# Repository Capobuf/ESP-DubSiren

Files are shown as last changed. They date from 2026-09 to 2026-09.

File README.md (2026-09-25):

# ESP32-S3 Dub Siren

Dub siren controllata da una GUI Windows. Il DSP gira interamente sull'ESP32-S3
e il PCM mono già elaborato può essere inviato al PC, a un DAC PCM5102A via
I2S, oppure a entrambe le destinazioni senza resampling.

Il motore V2 usa oscillatori pulse PolyBLEP, shaping RC mode-specifico,
saturazione asimmetrica e un LFO CLASSIC a carica/scarica esponenziale. Il
comando di debug `SET VOICING LEGACY|V2` permette il confronto a parità di
controlli; V2 è il default.

## Requisiti Windows

- ESP32-S3 DevKitC-1 collegata con un cavo USB dati
- modulo DAC PCM5102A per l'uscita audio GPIO
- VS Code con estensione PlatformIO IDE, oppure PlatformIO Core 6.x
- Python 3.11 o successivo (verificato con Python 3.13.14)
- uscita audio Windows

La configurazione usa il profilo PlatformIO base `esp32-s3-devkitc-1`, Hardware
CDC e USB Serial/JTAG. Non abilita PSRAM né imposta modalità flash specifiche.

## Preparazione

Aprire un prompt nella cartella `pc` ed eseguire una volta:

```bat
setup.bat
```

Lo script crea `.venv`, aggiorna pip e installa `pyserial` e `sounddevice`.

## Build e upload firmware

Da un terminale nella cartella `firmware`:

```powershell
python -m platformio run
python -m platformio run --target upload --upload-port COM6
```

Sostituire `COM6` con la porta effettiva. Usare la connessione USB nativa che
Windows identifica come Espressif USB Serial/JTAG (`VID 303A`, `PID 1001`), non
una porta Bluetooth. Al primo upload può essere necessario entrare nel
bootloader: tenere premuto **BOOT**, premere e rilasciare **RESET/EN**, quindi
rilasciare **BOOT**. Dopo l'upload, se resta nel bootloader, premere una volta
solo **RESET/EN**.

In VS Code sono equivalenti i comandi **PlatformIO: Build** e
**PlatformIO: Upload**.

## Collegamento PCM5102A

Il DAC usa I2S Philips standard a 48 kHz, stereo 16 bit. Il firmware duplica
ogni campione mono sui canali sinistro e destro; il PCM5102A ricava internamente
il clock necessario e non richiede MCLK dall'ESP32.

```text
ESP32 GPIO16 -> PCM5102A BCK
ESP32 GPIO17 -> PCM5102A LCK
ESP32 GPIO18 -> PCM5102A DIN
PCM5102A SCL/SCK -> GND
PCM5102A FMT -> GND
```

## Avvio

Dalla cartella `pc`:

```bat
run.bat
```

La GUI si apre anche senza ESP collegata. Poi:

1. premere **Refresh** e scegliere la COM Espressif;
2. scegliere **PC**, **PCM5102A** o **Both** nel selettore Output;
3. premere **Connect** e attendere `Connected · firmware 0.4.0`;
4. premere **Start Audio**;
5. usare **TRIGGER** oppure attivare **HOLD**.

**Stop Audio** arresta il flusso; **Disconnect** chiude ordinatamente audio,
thread e seriale. Per un controllo automatico dell'hardware collegato:

```powershell
.venv\Scripts\python.exe smoke_test.py COM6
```

Dettagli: [architettura](docs/architecture.md), [protocollo](docs/protocol.md) e
[controlli](docs/controls.md).

Per creare dieci brevi WAV di confronto direttamente dal PCM firmware (con la
scheda collegata), eseguire dalla cartella `pc`:

```powershell
.venv\Scripts\python.exe performance_capture.py COM6
```

Lo script stampa la directory temporanea che contiene i WAV. Usare
`--output-dir <percorso>` per scegliere una destinazione persistente. Il profilo
CLASSIC offre preset di progetto, non una riproduzione misurata di altri modelli.

## Test

```powershell
pc\.venv\Scripts\python.exe -m unittest discover -s pc -p "test_*.py"
pc\.venv\Scripts\python.exe tests\native\run.py
pc\.venv\Scripts\python.exe -m platformio run -d firmware
```

Il test nativo usa Zig C++ (`pip install ziglang`) oppure il compilatore indicato
da `CXX`; esegue parser e DSP senza scheda. Con hardware collegato, leggere
`renderUs`, `maxRenderUs`, `cycleUs` e `maxCycleUs` da STATUS durante gli scenari
di sweep e verificare che restino sotto 10.000 µs per blocco.

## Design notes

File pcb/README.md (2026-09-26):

# ESP-DubSiren PCB V0

Questa revisione e una piattaforma di verifica meccanica ed elettrica, non un progetto autorizzato alla fabbricazione. Serve a verificare nel materiale reale l'ingombro nel box Hammond 29830PSLA, l'ergonomia dei controlli, le forature, lo stack verticale e i due moduli montati sul retro.

## Stato della revisione

- PCB: 98.00 x 72.00 mm, angoli R6.00 mm, 2 layer, FR4 1.6 mm, rame standard.
- Origine PCB: angolo superiore sinistro dell'Edge.Cuts; X verso destra, Y verso il basso.
- Regole V0: clearance 0.20 mm, pista minima 0.20 mm, via 0.60/0.30 mm, foro-foro 0.25 mm.
- Controlli sul lato frontale; ESP32-S3 DevKitC-1 e breakout PCM5102A sul lato posteriore.
- I2S e alimentazioni sono instradati; GND e su entrambi i piani. I dieci segnali di controllo restano intenzionalmente non assegnati a GPIO.
- Il progetto e valido come V0 di verifica, ma **non deve essere mandato in produzione prima delle misure elencate sotto**.

## Box e derivazione delle dimensioni PCB

Box di riferimento: Hammond / Eddystone 29830PSLA.

Dal drawing ufficiale:

- esterno: 120.80 x 95.50 x 33.80 mm;
- vano interno del corpo: 104.71 x 79.41 mm;
- zona interna del lid: 102.83 x 77.13 mm;
- profondita interna nominale del corpo: circa 29.70-30.00 mm;
- spessore coperchio: 2.10 mm;
- interassi dei quattro bossoli: 110.75 x 85.75 mm.

La PCB 98 x 72 mm lascia rispetto alla zona interna del lid 4.83 mm totali in X e 5.13 mm totali in Y, cioe circa 2.42 e 2.57 mm per lato se centrata. Rispetto al vano del corpo lascia circa 3.36 mm per lato in X e 3.71 mm per lato in Y. Gli angoli R6 evitano i bossoli; il margine geometrico minimo tra arco PCB e bossolo nominale e circa 6.3 mm.

`MECH1`, centrato in (49, 36), e un riferimento board-only: su `Dwgs.User` contiene perimetro esterno, vano interno, zona interna del lid e quattro bossoli. Il modello STEP Hammond ufficiale e associato allo stesso riferimento, ruotato per allineare il piano del box alla PCB. Lo STEP rappresenta il box chiuso e quindi oscura la scheda nelle viste dall'alto; le immagini separate mostrano sia la scheda sia l'accoppiamento del box.

Fonti ufficiali:

- [Hammond 29830PSLA drawing](https://www.hammfg.com/files/parts/pdf/29830PSLA.pdf?v=1704738244)
- [Hammond 29830PSLA STEP](https://www.hammfg.com/files/parts/stp/29830PSLA.zip?v=1697661995)
- [Espressif ESP32-S3-DevKitC-1 user guide](https://docs.espressif.com/projects/esp-dev-kits/en/latest/esp32s3/esp32-s3-devkitc-1/user_guide_v1.0.html)
- [Espressif ESP32-S3-DevKitC-1 dimensional drawing](https://dl.espressif.com/dl/DXF_ESP32-S3-DevKitC-1_V1_20210312CB.pdf)
- [ALPS Alpine RK09L official catalog](https://tech.alpsalpine.com/cms.media/product_catalog_rv_01_rk09l_en_b8437bd47d.pdf)
- [E-Switch PB300STQ product page](https://www.e-switch.com/product/pb300-series-long-travel-pushbutton-switch/?part-number=PB300STQ)
- [E-Switch PB300STQ drawing T003000 Rev. B](https://configured-product-images.s3.amazonaws.com/2D/specs/PB300STQ.pdf)
- [E-Switch PB300STQ STEP](https://configured-product-images.s3.amazonaws.com/stp3dmodels/PB300STQ.stp)

## Layout e coordinate

Le coordinate dei potenziometri sono i centri degli alberi, non l'origine del footprint KiCad. Le coordinate dei pulsanti sono i centri degli attuatori.

| Ref | Funzione | X mm | Y mm | Lato |
|---|---|---:|---:|---|
| RV1 | TUNE | 20.00 | 14.00 | Front |
| RV2 | LFO RATE | 49.00 | 14.00 | Front |
| RV3 | DELAY TIME | 78.00 | 14.00 | Front |
| RV4 | FEEDBACK | 20.00 | 36.00 | Front |
| RV5 | ECHO LEVEL | 49.00 | 36.00 | Front |
| RV6 | MASTER | 78.00 | 36.00 | Front |
| SW2 | MOD DOWN | 14.00 | 58.50 | Front |
| SW1 | TRIGGER | 37.33 | 58.50 | Front |
| SW3 | MOD UP | 60.67 | 58.50 | Front |
| SW4 | ECHO CUT | 84.00 | 58.50 | Front |

La distanza tra gli assi dei potenziometri e 29 mm in X e 22 mm in Y. I pulsanti sono separati di circa 23.33 mm; TRIGGER e in seconda posizione ed e il comando piu immediato per la mano destra o sinistra.

Posizioni dei moduli:

| Ref | Modulo | X mm | Y mm | Rotazione | Lato | Nota |
|---|---|---:|---:|---:|---|---|
| U1 | ESP32-S3-DevKitC-1 N16R8 | 62.00 | 36.00 | 90 deg | Back | USB-C verso la parete destra; proiezione su `Dwgs.User`/`Cmts.User` |
| U2 | PCM5102A breakout | 18.00 | 36.00 | 0 deg | Back | footprint provvisorio, da sostituire dopo misura |
| MECH1 | Hammond 29830PSLA reference | 49.00 | 36.00 | 0 deg | board-only | sagoma e STEP ufficiale |

La DevKit e ruotata sul retro. La sua proiezione X/Y si sovrappone ai controlli frontali, ma i fori non coincidono. Il progetto assume montaggio su socket rialzato e terminali dei controlli rifilati: e una condizione di stack, non una collisione planare autorizzata automaticamente.

## Schema V0

Collegamenti gia formalizzati dal firmware:

- GPIO16 -> `I2S_BCLK` -> PCM5102A BCK;
- GPIO17 -> `I2S_LRCK` -> PCM5102A LCK;
- GPIO18 -> `I2S_DATA` -> PCM5102A DIN;
- MCLK non usato.

Il breakout PCM usa +5 V su VCC, +3V3 su XMT e GND su GND/FLT/DMP/SCL/FMT, coerentemente con le indicazioni gia presenti nel repository. Il suo pin 3V3 e marcato NC. Non e stato aggiunto alcun ADC.

I net `POT_*` e `BTN_*` sono presenti ma terminano intenzionalmente sul solo controllo; l'assegnazione ai GPIO sara definita nella revisione elettrica successiva.

## Footprint e simboli

Creati nel progetto:

- `ESP-DubSiren:ESP32-S3-DevKitC-1_N16R8`: 44 pin THT, corpo ufficiale 25.40 x 62.74 mm, passo 2.54 mm e file di proiezione USB. Il courtyard 2D e omesso intenzionalmente sulla V0 perche l'assemblaggio e su due livelli Z; la sagoma reale resta su Fab/Silk/Dwgs e la verifica va fatta con lo stack fisico.
- `ESP-DubSiren:PCM5102A_BREAKOUT_PROVISIONAL`: singola fila 11 pin, 31.8 x 23.8 mm e passo 2.54 mm **solo come placeholder da verificare**.
- `ESP-DubSiren:PB300STQ`: foratura e corpo dal drawing ufficiale; pad elettrici KiCad 1/2 corrispondenti ai due terminali fisici del disegno, piu ancoraggi e foro di posizionamento. STEP ufficiale associato.
- `ESP-DubSiren:Hammond_29830PSLA_REFERENCE`: riferimento senza pad, escluso da BOM e position file, con sagome e STEP ufficiale.
- simboli di progetto per ESP32-S3-DevKitC-1 e breakout PCM5102A.

Per `RK09L1140A5L` e usato il footprint standard KiCad `Potentiometer_THT:Potentiometer_Alps_RK09L_Single_Vertical`, la cui descrizione include esplicitamente il modello 1140A5L. Include pin, ancoraggi meccanici, corpo, albero e courtyard.

## Componenti provisional

- **PCM5102A breakout:** footprint, ingombro, passo e orientamento non sono affidabili senza il modulo acquistato.
- **PB300STQ:** geometria del footprint ricavata dal documento ufficiale, ma la scelta del componente resta provvisoria e deve essere confermata sul campione.
- **Stack ESP32:** il footprint planare e ufficiale; socket, pin strip e altezza massima della variante N16R8 montata non sono definiti.
- **Posizione del foro USB nel box:** e indicata solo come parete candidata; nessun foro box e stato progettato.

## Verifica 3D e altezza

La verifica planare con la sagoma ufficiale non mostra interferenze con pareti o bossoli. DRC e placement score confermano Edge.Cuts e posizioni; lo STEP Hammond allineato mostra che la PCB resta dentro il perimetro utile.

La verifica verticale non e conclusiva: non esistono nel progetto modelli 3D affidabili del breakout PCM acquistato e dell'esatto sistema DevKit + socket. Una stima conservativa per il ramo peggiore e:

- PB300STQ sopra PCB: 10.6 mm nominali dal drawing;
- PCB: 1.6 mm;
- DevKit su socket sul retro: circa 12-14 mm, dipendente dal socket e dai componenti;
- stack stimato: circa 24.2-26.2 mm contro circa 29.7 mm di profondita interna nominale;
- margine teorico: circa 3.5-5.5 mm, prima di tolleranze, saldature, pin sporgenti e fissaggio PCB.

Questa stima suggerisce fattibilita, ma non prova l'assenza di collisioni Z. In particolare, la DevKit deve essere rialzata sopra le code dei pin THT frontali e tali code devono essere rifilate.

## ERC e DRC

Risultati finali salvati in `erc-v0.json` e `drc-v0.json`:

- ERC: 0 errori, 10 warning. Sono esclusivamente le 10 label isolate `POT_*` e `BTN_*`, intenzionali per non inventare il pinout GPIO.
- DRC: 0 errori, 0 unconnected items, 29 warning.
- Placement score Konnect: 100/100, nessuna hard failure, Edge.Cuts presente.

I 29 warning DRC sono documentati:

- 8 `lib_footprint_mismatch`: limite del refresh typed Konnect/KiCad per footprint standard con zone e per istanze custom aggiornate/flippate;
- 8 `silk_over_copper`: reference designator automatici dei quattro PB300STQ sopra i propri pad; le etichette funzione restano leggibili sotto i pulsanti;
- 12 `footprint_symbol_field_mismatch`: campi Description/Datasheet presenti nello schema ma non replicati nei footprint;
- 1 `extra_footprint`: `MECH1`, intenzionalmente board-only e assente dallo schema.

Non restano short, errori di clearance, collisioni di foratura, piste incrociate, courtyard overlap critici o connessioni non instradate.

## Measurements to verify before fabrication

1. Breakout PCM5102A acquistato: lunghezza, larghezza, altezza massima, passo reale, offset del primo pin, ordine/orientamento degli 11 pin e lato di montaggio.
2. DevKit N16R8 reale: dimensioni massime inclusi USB-C, BOOT/RESET e componenti; altezza dei pin header; tipo e altezza dei socket che saranno usati.
3. Distanza reale tra PCB principale e DevKit/PCM sul retro; lunghezza residua delle code THT di potenziometri e pulsanti dopo saldatura.
4. RK09L1140A5L acquistati: lunghezza boccola/filetto, rondella e dado, altezza corpo sotto pannello, diametro e tolleranza del foro pannello.
5. PB300STQ acquistati: variante esatta, altezza attuatore a riposo/premuto, corsa, eventuale keycap e foro/apertura nel coperchio.
6. Hammond reale: vano interno, raggi di fusione, posizione/diametro bossoli, planarita del lid e quota realmente disponibile tra lid, PCB e fondo.
7. Metodo di fissaggio PCB: distanziali, adesivi o staffe; la V0 non aggiunge fori di montaggio perche i bossoli Hammond sono esterni al perimetro PCB.
8. Posizione del taglio USB-C sulla parete destra dopo aver montato socket e DevKit; verificare anche accesso a BOOT e RESET.
9. Prova completa dello stack chiuso con plastilina/calibro: lid -> controlli -> PCB -> socket/moduli -> fondo, includendo saldature e tolleranze.

## Immagini

- `screenshots/pcb-top.png`: plot 2D top della PCB.
- `screenshots/pcb-3d-top.png`: vista 3D ortogonale della scheda senza il box opaco.
- `screenshots/pcb-3d-iso.png`: vista 3D isometrica della scheda senza il box opaco.
- `screenshots/enclosure-fit-top.png`: accoppiamento XY con lo STEP Hammond e i quattro bossoli.
- `screenshots/enclosure-fit-3d.png`: vista prospettica del riferimento Hammond chiuso.
- `screenshots/schematic-v0.png`: schema elettrico V0.

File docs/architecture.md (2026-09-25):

# Architecture

## Data flow

```text
tkinter controls
      |
newline commands over USB
      |
CommandParser -> synchronized ControlStore
                         |
                  block snapshot
                         |
ControlState -> AudioEngine -> pulse PolyBLEP -> RC voicing -> DC blocker
                                      |                         |
                                      +-> Envelope -------------+
                                      |
                                      +-> Delay -> HPF -> LPF -> feedback saturation
                                                   |
                              dry + wet -> master -> soft clip -> int16
                                                                      |
                                                        mono int16 PCM block
                                                            /         \
                                                   UsbPcmSink    I2sPcm5102Sink
                                                        |               |
                                             binary PCM over USB   stereo I2S
                                                        |               |
                                                RawOutputStream      PCM5102A
```

`audioTask` produces exactly 480 mono samples per iteration and is paced with
`vTaskDelayUntil` every 10 ms. The DSP uses floats internally and converts to
signed little-endian int16 only at the final output. The task takes one locked
snapshot of `ControlState` at each block boundary; command parsing never mutates
the state concurrently.

`AudioEngine` includes no USB, Python or PCM5102A dependencies. Its one rendered
block is routed through the `AudioSink` interface to `UsbPcmSink`,
`I2sPcm5102Sink`, or both. `UsbPcmSink` adds the binary framing and serializes
AUDIO and STATUS writes with a mutex. STATUS remains available over USB even
when USB AUDIO packets are disabled. Hardware CDC's TX ring is set to 8192 bytes
before USB startup, so a 970-byte audio packet can be queued without waiting
for the default 256-byte ring to drain. Packet writes complete any partial
`Serial.write` before another packet starts.

`I2sPcm5102Sink` duplicates each of the 480 mono int16 samples into a stereo
left/right frame and writes the resulting 960 values to I2S DMA. ESP32-S3 is
the 48 kHz, 16-bit Philips-I2S master TX on GPIO16 BCLK, GPIO17 LRCK and GPIO18
DATA. MCLK and DIN are unused. Four DMA buffers each hold 480 stereo frames;
the audio task remains paced at one rendered block every 10 ms.

The one-second delay is a fixed 48,000-sample int16 ring buffer in internal RAM
(96 kB). It does not use or require PSRAM. Delay reads are fractional and use
linear interpolation. Delay time follows a 25 ms one-pole smoother limited to
2000 ms of delay movement per second. A live sweep therefore bends pitch without
jumping the read head. HPF and LPF are local RBJ biquads with Q 1.0;
their cutoffs follow 18 ms smoothing and coefficients refresh every 64 samples
without resetting filter state. The feedback path uses
asymmetric saturation before the delay write, while the existing cubic
`softClip` remains the final safety limiter.

`SmoothedParameter` handles sample-rate tune, depth, rate, feedback, echo level,
master, delay and filter cutoff changes. The LFO retains phase across shape
changes and fades the modulation offset over 10 ms. Mode changes render both
voicings at the same oscillator phase for a 6 ms crossfade. Neither transition
resets the delay or its feedback state. CLASSIC preset selection happens inside
the firmware; EXTENDED retains the full control state for switching back.

The V2 oscillator starts from a variable-duty band-limited pulse. SINE1 uses
three tracking one-poles; SINE2 uses two with a higher tracking ratio and more
asymmetry. TEST_TONE adds a click-free rhythmic gate. SQUARE selects high/low
frequency targets with a 2.5 ms anti-click slew while preserving oscillator
phase. Filter coefficients are refreshed every 16 samples; measured render
telemetry is exposed in STATUS as `renderUs` and `maxRenderUs`. `cycleUs` and
`maxCycleUs` measure rendering plus the selected output writes.

The preset pitch, rate, RC curves, smoothing, voicing and saturation constants
are project tuning points. Timbre calibration against a physical instrument
remains future work requiring recordings or measurements. No circuit or audio
identity with a third-party device is claimed.

## PC concurrency

- tkinter runs only on the main thread;
- `SerialTransport` owns a reader thread and a resynchronizing packet parser;
- a bounded 12-block queue drops the oldest PCM when full;
- `AudioPlayer` owns the `sounddevice.RawOutputStream` thread and writes silence
  if a block is temporarily unavailable.

The PC has no oscillator, LFO, envelope, delay or filter implementation.

## Output routing

`STREAM 0` disables both audio destinations without stopping USB control.
`STREAM 1` sends the same rendered block according to the atomic output mode:

```text
                         +-> UsbPcmSink -> PC
AudioEngine -> PCM ------+
                         +-> I2sPcm5102Sink -> PCM5102A
```

`SET OUTPUT PC|GPIO|BOTH` changes the destinations at a block boundary without
restarting `AudioEngine` or resetting oscillator, envelope, delay, or filters.

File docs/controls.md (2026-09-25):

# Controls

The firmware's absolute DSP/protocol range is intentionally wider than the
performance range exposed by the desktop UI. The GUI maps its normalized
slider position to a physical value and sends that value, in the units shown,
over USB. It never sends the normalized position.

The Profile selector offers **CLASSIC** and **EXTENDED**. EXTENDED exposes the
complete set of continuous controls below. CLASSIC shows Mode, three Pitch
positions, four Modulation positions, the performance buttons, delay, feedback,
echo level, echo HPF/LPF, Echo Cut and Master. CLASSIC fixes LFO depth to 1 octave,
decay to 120 ms, and uses the RC-like LFO shape. MANUAL enables MOD DOWN and
MOD UP; automatic modulation disables them. The firmware applies these preset
values even when controlled without the desktop UI. Returning to EXTENDED
restores its retained tune, rate, shape, depth and decay settings.

| CLASSIC selector | Project preset |
|---|---:|
| Pitch LOW / MID / HIGH | 110 / 220 / 440 Hz |
| Modulation SLOW / MEDIUM / FAST | 0.35 / 0.70 / 2.80 Hz |
| Modulation MANUAL | RC response to MOD DOWN / MOD UP |

These are internal starting values derived from the project's range, not
measurements of another siren. They and the RC charge/fall ratios are centralized
for later listening-based calibration.

| Control | Absolute DSP/protocol range | Performance UI range / default | UI mapping |
|---|---|---|---|
| Mode | SINE1 | SINE1 | rounded SINE1, brighter SINE2, gated TEST_TONE, high/low SQUARE |
| Tune | 30–9000 Hz | 80–1600 Hz / 220 Hz | logarithmic |
| LFO Shape | CLASSIC | CLASSIC | RC-like CLASSIC, eight geometric shapes, plus MANUAL |
| LFO Rate | 0.05–20 Hz | 0.15–8 Hz / 0.70 Hz | logarithmic |
| LFO Depth | 0–2 oct | 0–1.25 oct / 1 oct | linear; exponential musical pitch modulation remains in the DSP |
| Decay | 0–3000 ms | 0–1500 ms / 120 ms | quadratic, with more travel for short decays |
| Delay Time | 50–1000 ms | 50–1000 ms / 360 ms | linear; smoothed fractional read position |
| Feedback | 0–1.05 | 0–1.05 / 0.62 | power curve, exponent 0.8; values above one retain protected self-oscillation |
| Echo Level | 0–1 | 0–1 / 0.45 | linear wet level |
| High Pass | 50–7000 Hz | 50–4000 Hz / 60 Hz | logarithmic, echo path only |
| Low Pass | 200–19000 Hz | 400–16000 Hz / 7000 Hz | logarithmic, echo path only |
| Master | 0–1 | 0–1 / 0.50 | linear final gain before soft limiter |

`TRIGGER`, `MOD DOWN`, `MOD UP` and `ECHO CUT` are momentary. A global mouse
release handler releases them even if the pointer leaves the widget. `HOLD` is
a toggle and keeps the envelope gate open.

The CLASSIC LFO alternates between +1 and -1 through unequal RC-like charge and
fall curves. The manual modulation buttons are enabled only for MANUAL: UP
targets +1, DOWN targets -1, neither or both target zero through the same
charge/fall model.

SQUARE uses the LFO phase as a high/low selector and applies only a 2.5 ms
anti-click pitch slew. TEST_TONE uses the LFO as a half-cycle gate with 2 ms
attack and 4 ms release.

ECHO CUT mutes only the wet output. It does not clear or stop the delay line, so
the tail returns on release. Tune (12 ms), depth (15 ms), LFO rate (20 ms),
feedback (18 ms), echo level and master (15 ms), delay time (25 ms), and echo
filter cutoffs (18 ms) are smoothed in firmware. Delay movement is additionally
limited to 2000 ms/s while fractional reads preserve pitch bending. LFO shape
and Siren Mode transitions last 10 ms and 6 ms respectively. Slider commands are throttled to approximately
25 ms during dragging and the final release value is sent immediately.

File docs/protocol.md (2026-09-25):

# USB protocol

The device uses Arduino Hardware CDC / USB Serial-JTAG. Control traffic from PC
to ESP is ASCII, newline-delimited. ESP-to-PC traffic is binary only; firmware
does not print diagnostic text into the PCM stream.

## PC to ESP

Connection commands:

```text
HELLO
STREAM 1
STREAM 0
SET OUTPUT PC|GPIO|BOTH
```

`STREAM` is the global audio enable. With streaming enabled, `PC` emits USB
AUDIO packets, `GPIO` writes only to the PCM5102A I2S sink, and `BOTH` writes
the same rendered PCM block to both sinks. In GPIO-only mode USB remains active
for commands, HELLO, STATUS, controls, and triggers.

Control commands:

```text
SET MODE SINE1|SINE2|TEST_TONE|SQUARE
SET PROFILE CLASSIC|EXTENDED
SET CLASSIC_PITCH LOW|MID|HIGH
SET CLASSIC_MOD SLOW|MEDIUM|FAST|MANUAL
SET TUNE_HZ <30..9000>
SET LFO_SHAPE CLASSIC|TRIANGLE|SQUARE|SAW_UP|SAW_DOWN|ASYM_UP|ASYM_DOWN|PULSE_25|PULSE_75|MANUAL
SET LFO_RATE_HZ <0.05..20>
SET LFO_DEPTH_OCT <0..2>
SET DECAY_MS <0..3000>
SET DELAY_MS <50..1000>
SET FEEDBACK <0..1.05>
SET ECHO_LEVEL <0..1>
SET HPF_HZ <50..7000>
SET LPF_HZ <200..19000>
SET MASTER <0..1>
TRIGGER 0|1
HOLD 0|1
MOD_UP 0|1
MOD_DOWN 0|1
ECHO_CUT 0|1
```

Development A/B command (V2 is the boot default):

```text
SET VOICING LEGACY|V2
```

These limits are the absolute DSP/protocol ranges. The desktop GUI exposes a
narrower performance range for selected controls, but still sends physical
values such as `SET TUNE_HZ 220.0`; normalized slider positions are never part
of the protocol. Finite numeric values are clamped to the absolute ranges.
Malformed and unknown commands are ignored. Parsing occurs outside the audio
task.

The boot profile is EXTENDED for compatibility. CLASSIC uses firmware presets:
LOW/MID/HIGH = 110/220/440 Hz, SLOW/MEDIUM/FAST = 0.35/0.70/2.80 Hz,
depth = 1 octave, decay = 120 ms and the RC-like LFO. MANUAL selects the same
RC manual response as the extended MANUAL shape. Existing continuous settings
remain stored while CLASSIC is active and take effect again in EXTENDED.
Profile, mode and shape changes preserve the oscillator phase and echo tail.

## ESP to PC

Every packet begins with this packed, 10-byte little-endian header:

| Offset | Field | Type | Value |
|---:|---|---|---|
| 0 | magic | 2 bytes | `DS` |
| 2 | version | uint8 | `1` |
| 3 | type | uint8 | AUDIO `0x01`, STATUS `0x02` |
| 4 | payload length | uint16 | bytes |
| 6 | sequence | uint32 | increments per packet type |

An AUDIO payload is always 960 bytes: 480 signed int16 mono PCM samples at
48,000 Hz. A STATUS payload is UTF-8 JSON. `HELLO` currently returns:

```json
{"name":"DubSiren","protocol":1,"sampleRate":48000,"blockSamples":480,"firmware":"0.4.0","renderUs":0,"maxRenderUs":0,"cycleUs":0,"maxCycleUs":0,"maxUsbWriteUs":0,"maxI2sWriteUs":0,"output":"BOTH","i2sReady":true}
```

Timing zeros above are placeholders, not measured performance. `renderUs` is the
most recent 480-sample render time and `maxRenderUs` is the
maximum observed since boot. `cycleUs` and `maxCycleUs` include selected output
writes. `maxUsbWriteUs` and `maxI2sWriteUs` isolate the maximum time spent in
each output write. `output` reports the active routing selection and `i2sReady` reports
whether I2S initialization succeeded. These are diagnostic/status additions;
packet framing and protocol version remain unchanged.

There is no CRC because USB is the reliable transport. The Python parser scans
again for `DS` after invalid data or lost framing and rejects AUDIO payloads of
the wrong length.

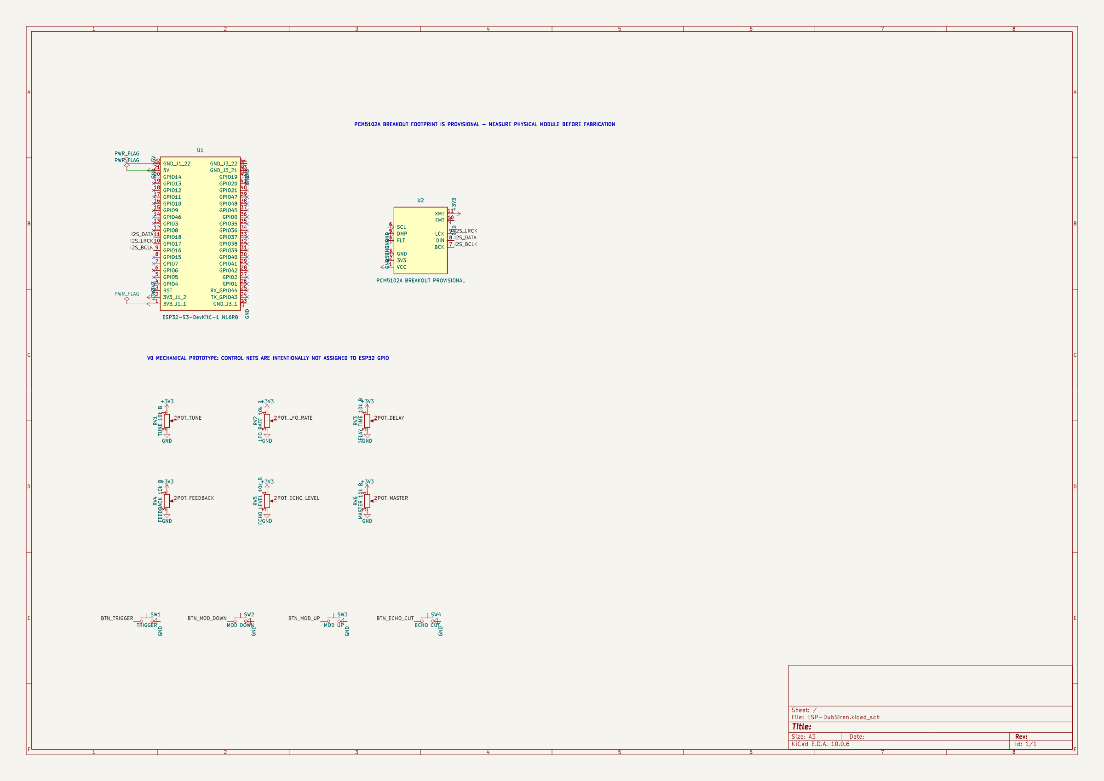
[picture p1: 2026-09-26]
pcb/screenshots/schematic-v0.png

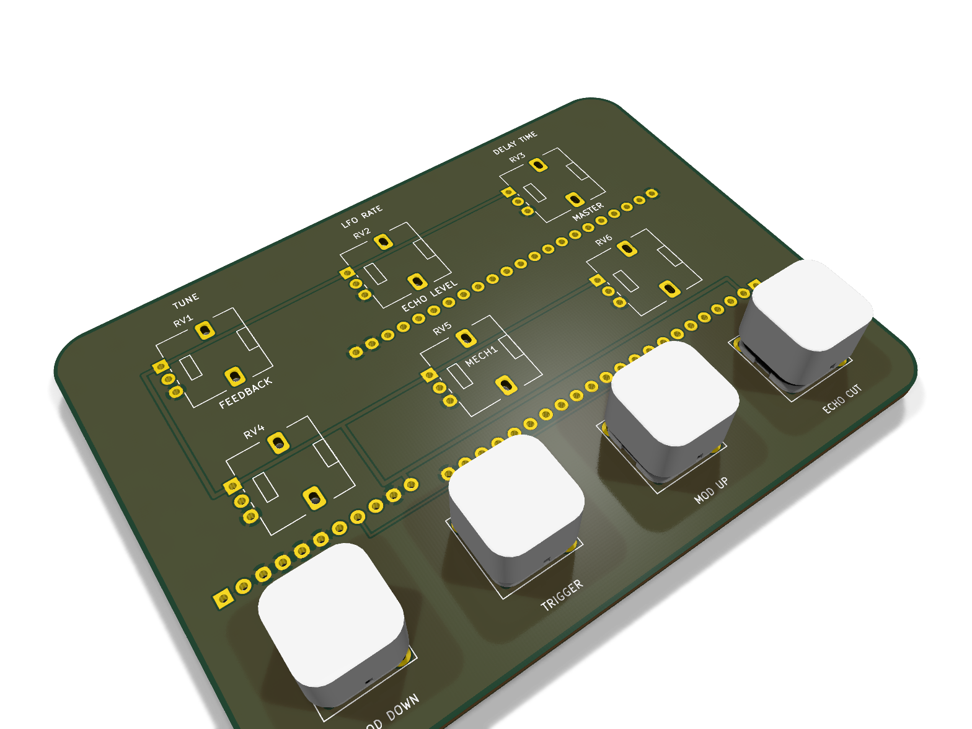
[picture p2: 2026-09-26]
pcb/screenshots/pcb-3d-iso.png

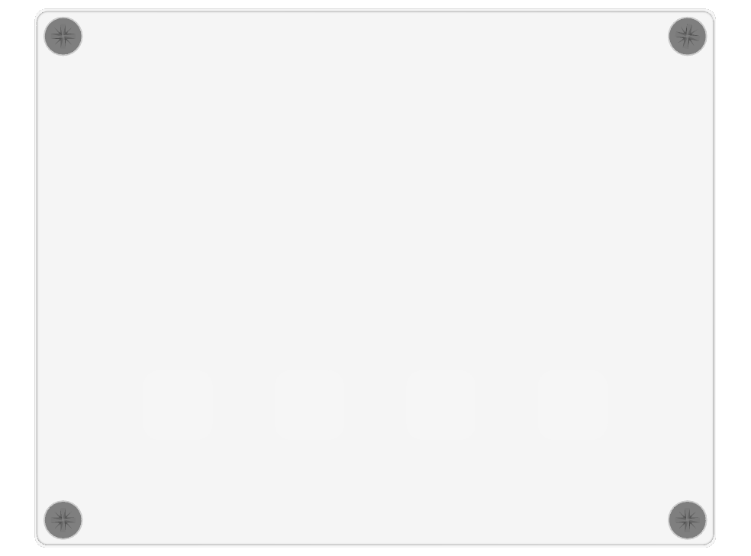
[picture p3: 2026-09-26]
pcb/screenshots/enclosure-fit-top.png

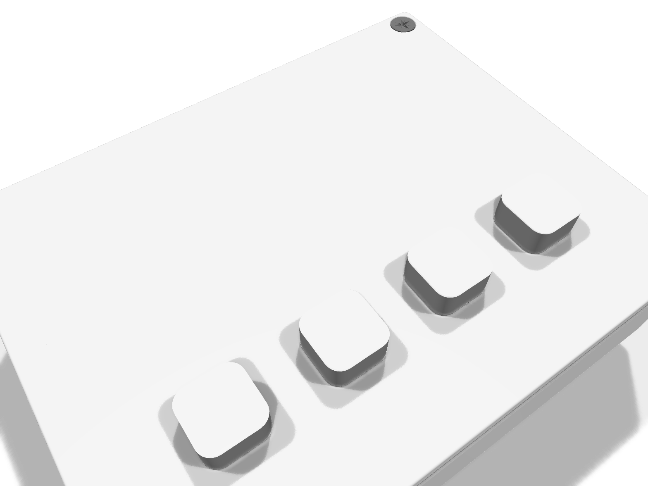
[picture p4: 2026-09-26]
pcb/screenshots/enclosure-fit-3d.png

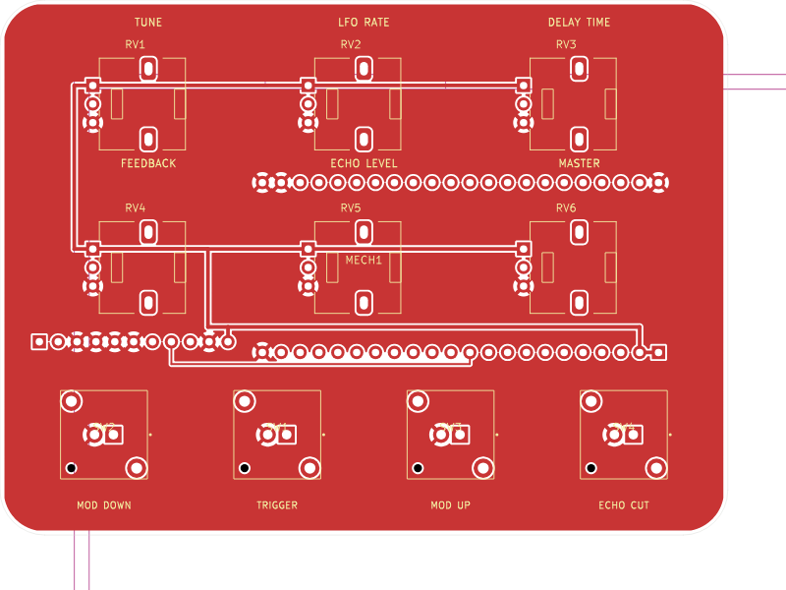
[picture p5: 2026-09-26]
pcb/screenshots/pcb-top.png

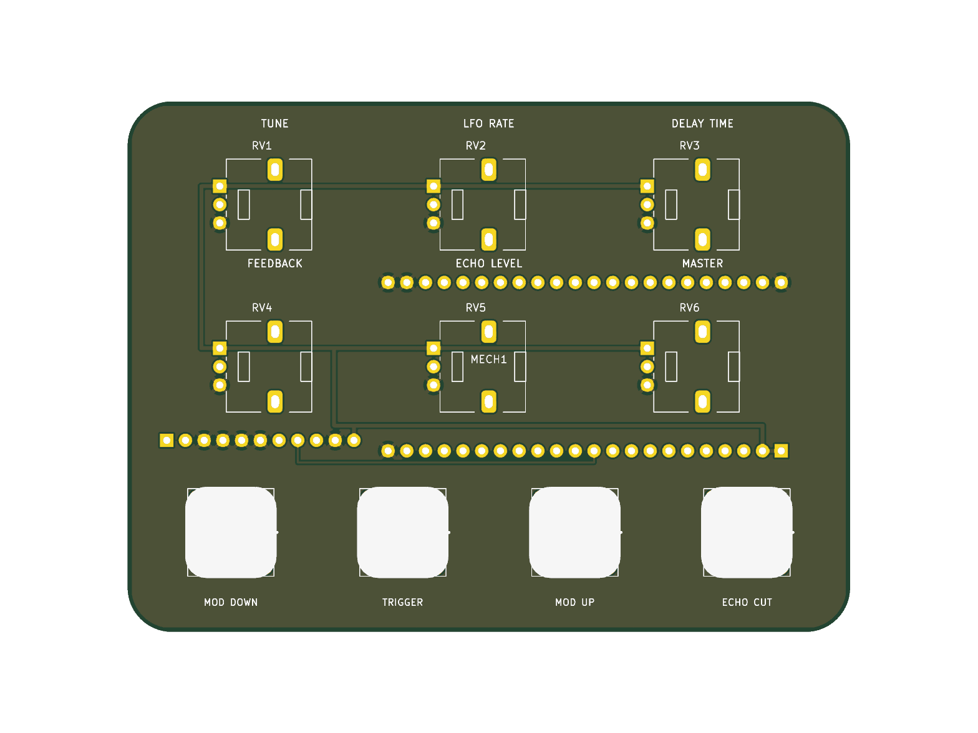
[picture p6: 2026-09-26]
pcb/screenshots/pcb-3d-top.png

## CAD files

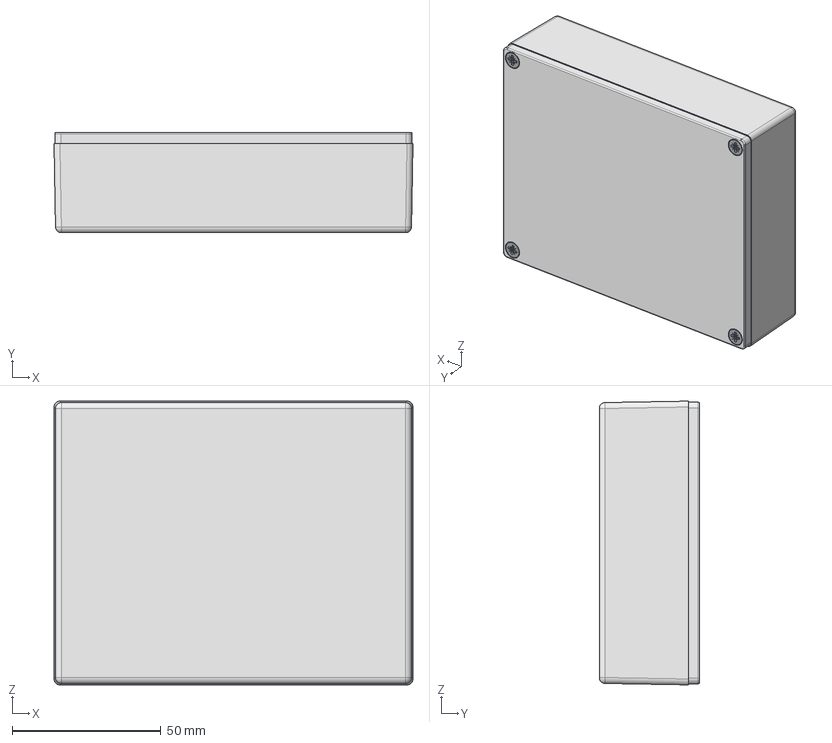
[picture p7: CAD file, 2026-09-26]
pcb/3dmodels/Hammond_29830PSLA.stp
120.8 x 33.8 x 95.5 mm
26827P BOX M
26357P LID m
Eddystone Pozi (screw M3.5-0.6X 12mm FH) x 4

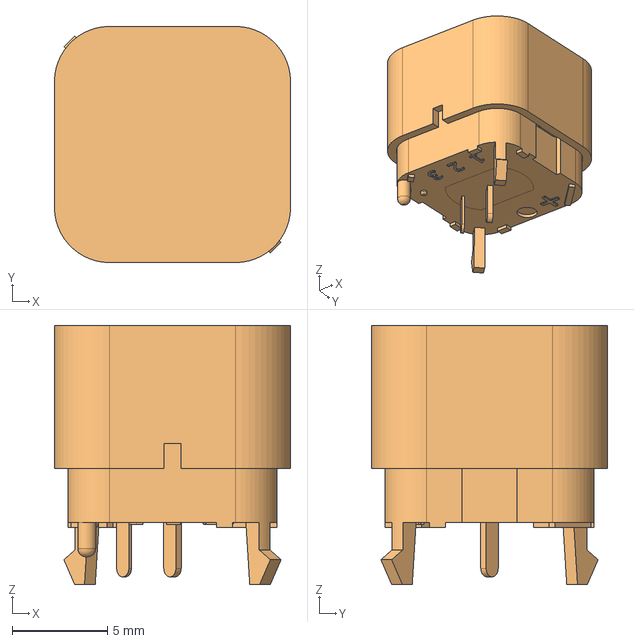
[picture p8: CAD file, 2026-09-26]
pcb/3dmodels/PB300STQ.stp
12.4 x 12.4 x 13.6 mm

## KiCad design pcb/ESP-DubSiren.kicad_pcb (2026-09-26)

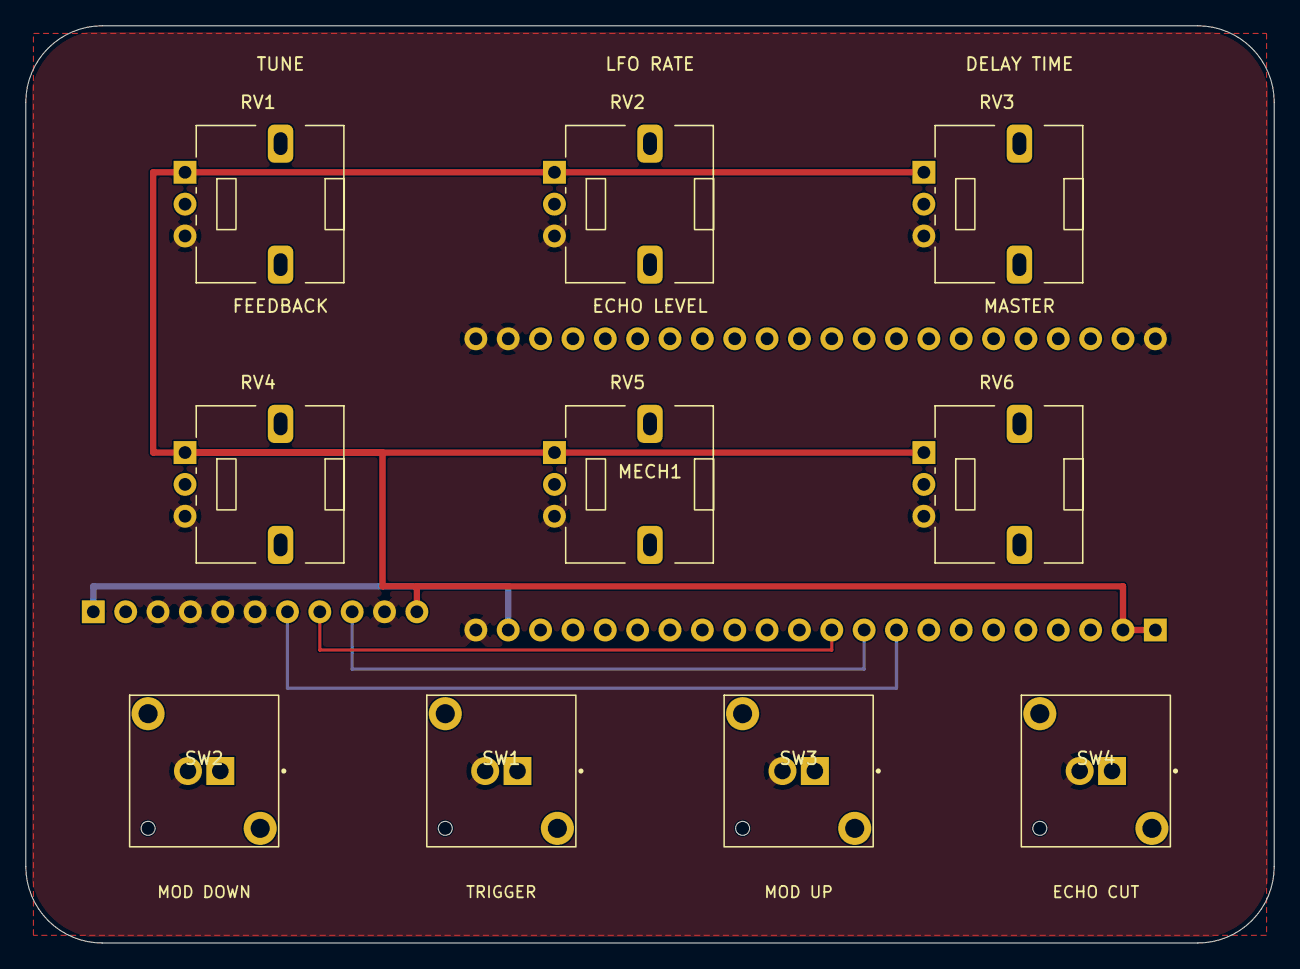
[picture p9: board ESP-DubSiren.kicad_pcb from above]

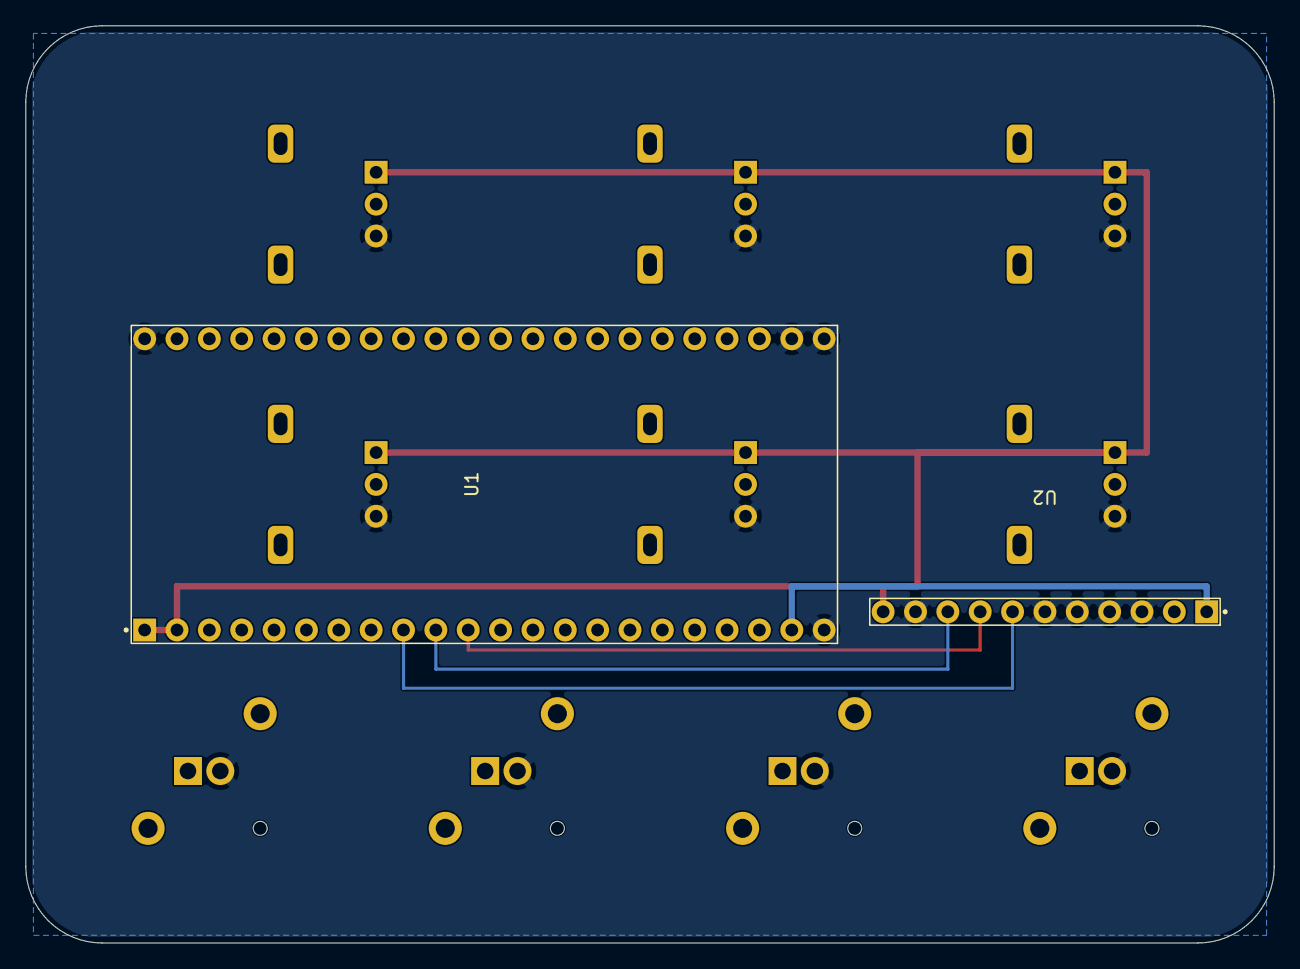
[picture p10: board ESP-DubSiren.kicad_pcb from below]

Board: 2 copper layers, 98.0 x 72.0 mm, 13 parts (2 on the bottom side), 6 nets.

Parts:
MECH1: Hammond_29830PSLA_REFERENCE
RV1: TUNE 10k B; Potentiometer_Alps_RK09L_Single_Vertical
RV2: LFO RATE 10k B; Potentiometer_Alps_RK09L_Single_Vertical
RV3: DELAY TIME 10k B; Potentiometer_Alps_RK09L_Single_Vertical
RV4: FEEDBACK 10k B; Potentiometer_Alps_RK09L_Single_Vertical
RV5: ECHO LEVEL 10k B; Potentiometer_Alps_RK09L_Single_Vertical
RV6: MASTER 10k B; Potentiometer_Alps_RK09L_Single_Vertical
SW1: TRIGGER; PB300STQ
SW2: MOD DOWN; PB300STQ
SW3: MOD UP; PB300STQ
SW4: ECHO CUT; PB300STQ
U1: ESP32-S3-DevKitC-1 N16R8; ESP32-S3-DevKitC-1_N16R8
U2: PCM5102A BREAKOUT PROVISIONAL; PCM5102A_BREAKOUT_PROVISIONAL

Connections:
+3V3: RV1.1, RV2.1, RV3.1, RV4.1, RV5.1, RV6.1, U1.1, U1.2, U2.11
+5V: U1.21, U2.1
/I2S_BCLK: U1.9, U2.7
/I2S_DATA: U1.11, U2.8
/I2S_LRCK: U1.10, U2.9
GND: RV1.3, RV2.3, RV3.3, RV4.3, RV5.3, RV6.3, SW1.2, SW2.2, SW3.2, SW4.2, U1.22, U1.23, U1.43, U1.44, U2.3, U2.4, U2.5, U2.6, U2.10

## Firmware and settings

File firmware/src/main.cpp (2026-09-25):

#include <Arduino.h>
#include <atomic>

#include "Config.h"
#include "audio/AudioEngine.h"
#include "control/CommandParser.h"
#include "output/I2sPcm5102Sink.h"
#include "output/UsbPcmSink.h"

namespace {

enum class OutputMode : uint8_t {
    Pc,
    Gpio,
    Both,
};

UsbPcmSink usbSink;
I2sPcm5102Sink i2sSink;
AudioEngine engine;
ControlStore controls;
CommandParser commandParser(controls);
std::atomic<bool> streamEnabled{false};
std::atomic<OutputMode> outputMode{OutputMode::Both};
std::atomic<uint32_t> lastRenderUs{0};
std::atomic<uint32_t> maximumRenderUs{0};
std::atomic<uint32_t> lastCycleUs{0};
std::atomic<uint32_t> maximumCycleUs{0};
std::atomic<uint32_t> maximumUsbWriteUs{0};
std::atomic<uint32_t> maximumI2sWriteUs{0};
bool i2sReady = false;
String commandBuffer;

const char *outputModeName(OutputMode mode) {
    switch (mode) {
        case OutputMode::Pc:
            return "PC";
        case OutputMode::Gpio:
            return "GPIO";
        case OutputMode::Both:
            return "BOTH";
    }
    return "PC";
}

bool parseOutputMode(const String &value, OutputMode &mode) {
    if (value == "PC") {
        mode = OutputMode::Pc;
    } else if (value == "GPIO") {
        mode = OutputMode::Gpio;
    } else if (value == "BOTH") {
        mode = OutputMode::Both;
    } else {
        return false;
    }
    return true;
}

void updateMaximum(std::atomic<uint32_t> &maximum, uint32_t value) {
    uint32_t observed = maximum.load(std::memory_order_relaxed);
    while (value > observed &&
           !maximum.compare_exchange_weak(observed, value,
                                          std::memory_order_relaxed)) {
    }
}

void sendStatus() {
    const OutputMode mode = outputMode.load(std::memory_order_relaxed);
    const String json =
        String("{\"name\":\"DubSiren\",\"protocol\":1,\"sampleRate\":") +
        Config::kSampleRate + ",\"blockSamples\":" + Config::kBlockSamples +
        ",\"firmware\":\"" + Config::kFirmwareVersion +
        "\",\"renderUs\":" + lastRenderUs.load(std::memory_order_relaxed) +
        ",\"maxRenderUs\":" +
        maximumRenderUs.load(std::memory_order_relaxed) +
        ",\"cycleUs\":" + lastCycleUs.load(std::memory_order_relaxed) +
        ",\"maxCycleUs\":" +
        maximumCycleUs.load(std::memory_order_relaxed) +
        ",\"maxUsbWriteUs\":" +
        maximumUsbWriteUs.load(std::memory_order_relaxed) +
        ",\"maxI2sWriteUs\":" +
        maximumI2sWriteUs.load(std::memory_order_relaxed) +
        ",\"output\":\"" + outputModeName(mode) +
        "\",\"i2sReady\":" + (i2sReady ? "true" : "false") + "}";
    usbSink.writeStatus(json.c_str(), json.length());
}

void handleCommand(String command) {
    command.trim();
    if (command == "HELLO") {
        sendStatus();
    } else if (command == "STREAM 1") {
        streamEnabled.store(true, std::memory_order_release);
    } else if (command == "STREAM 0") {
        streamEnabled.store(false, std::memory_order_release);
    } else if (command.startsWith("SET OUTPUT ")) {
        OutputMode requested;
        if (parseOutputMode(command.substring(11), requested) &&
            (requested == OutputMode::Pc || i2sReady)) {
            outputMode.store(requested, std::memory_order_release);
        }
    } else {
        commandParser.parse(command);
    }
}

void pollCommands() {
    while (Serial.available() > 0) {
        const char value = static_cast<char>(Serial.read());
        if (value == '\n') {
            handleCommand(commandBuffer);
            commandBuffer = "";
        } else if (value != '\r') {
            if (commandBuffer.length() < 127) {
                commandBuffer += value;
            } else {
                commandBuffer = "";
            }
        }
    }
}

void audioTask(void *) {
    int16_t block[Config::kBlockSamples];
    TickType_t nextWake = xTaskGetTickCount();
    bool i2sWasActive = false;

    while (true) {
        const uint32_t cycleStartUs = micros();
        const ControlState snapshot = controls.snapshot();
        const uint32_t renderStartUs = micros();
        engine.render(snapshot, block, Config::kBlockSamples);
        const uint32_t renderUs = micros() - renderStartUs;
        lastRenderUs.store(renderUs, std::memory_order_relaxed);
        updateMaximum(maximumRenderUs, renderUs);

        const bool enabled = streamEnabled.load(std::memory_order_acquire);
        const OutputMode mode = outputMode.load(std::memory_order_acquire);
        const bool pcActive =
            enabled && (mode == OutputMode::Pc || mode == OutputMode::Both);
        const bool i2sActive =
            enabled && i2sReady &&
            (mode == OutputMode::Gpio || mode == OutputMode::Both);
        if (pcActive) {
            const uint32_t writeStartUs = micros();
            usbSink.write(block, Config::kBlockSamples);
            updateMaximum(maximumUsbWriteUs, micros() - writeStartUs);
        }
        if (i2sActive) {
            const uint32_t writeStartUs = micros();
            i2sSink.write(block, Config::kBlockSamples);
            updateMaximum(maximumI2sWriteUs, micros() - writeStartUs);
        } else if (i2sWasActive) {
            i2sSink.silence();
        }
        i2sWasActive = i2sActive;

        const uint32_t cycleUs = micros() - cycleStartUs;
        lastCycleUs.store(cycleUs, std::memory_order_relaxed);
        updateMaximum(maximumCycleUs, cycleUs);
        vTaskDelayUntil(&nextWake, pdMS_TO_TICKS(Config::kBlockDurationMs));
    }
}

}  // namespace

void setup() {
    // One packet is 970 bytes; the driver's 256-byte default causes writes to
    // wait for USB during the audio task. Allocate the ring before CDC begins.
    Serial.setTxBufferSize(8192);
    Serial.begin(115200);
    commandBuffer.reserve(128);
    usbSink.begin();
    i2sReady = i2sSink.begin();
    if (!i2sReady) {
        outputMode.store(OutputMode::Pc, std::memory_order_relaxed);
    }
    engine.begin();
    xTaskCreatePinnedToCore(audioTask, "audio", 6144, nullptr, 2, nullptr, 1);
}

void loop() {
    pollCommands();
    delay(1);
}

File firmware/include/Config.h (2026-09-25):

#pragma once

#include <Arduino.h>

namespace Config {
constexpr uint32_t kSampleRate = 48000;
constexpr size_t kBlockSamples = 480;
constexpr uint32_t kBlockDurationMs = 10;
constexpr uint8_t kProtocolVersion = 1;
constexpr char kFirmwareVersion[] = "0.4.0";
constexpr int kI2sBclkPin = 16;
constexpr int kI2sLrckPin = 17;
constexpr int kI2sDataPin = 18;
}

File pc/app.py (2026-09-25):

import queue
import tkinter as tk
from tkinter import messagebox, ttk

from serial.tools import list_ports

from audio_player import AudioPlayer
from control_ranges import CONTROL_SPECS, ControlSpec
from protocol import PROTOCOL_VERSION
from transport import SerialTransport

OUTPUT_VALUES = {
    "PC": "PC",
    "PCM5102A": "GPIO",
    "Both": "BOTH",
}


class SliderControl(ttk.Frame):
    def __init__(
        self,
        parent: tk.Misc,
        label: str,
        command_name: str,
        spec: ControlSpec,
        callback,
    ) -> None:
        super().__init__(parent)
        self.command_name = command_name
        self.spec = spec
        self.callback = callback
        self.value = spec.default

        ttk.Label(self, text=label, width=12).grid(row=0, column=0, sticky="w")
        self.scale = tk.Scale(
            self,
            from_=0.0,
            to=1.0,
            resolution=0.001,
            orient=tk.HORIZONTAL,
            showvalue=False,
            highlightthickness=0,
            command=self._changed,
        )
        self.scale.grid(row=0, column=1, sticky="ew")
        self.value_label = ttk.Label(self, width=12, anchor="e")
        self.value_label.grid(row=0, column=2, sticky="e")
        self.columnconfigure(1, weight=1)
        self.scale.set(self._to_position(spec.default))
        self._show_value(spec.default)
        self.scale.bind("<ButtonRelease-1>", self._released)

    def _to_position(self, value: float) -> float:
        return self.spec.to_normalized(value)

    def _from_position(self, position: float) -> float:
        return self.spec.from_normalized(position)

    def _changed(self, position: str) -> None:
        self.value = self._from_position(float(position))
        self._show_value(self.value)
        self.callback(self.command_name, self.value, False)

    def _released(self, _event) -> None:
        self.callback(self.command_name, self.value, True)

    def _show_value(self, value: float) -> None:
        self.value_label.configure(text=self.spec.formatter(value))


class DubSirenApp:
    def __init__(self, root: tk.Tk) -> None:
        self.root = root
        self.root.title("ESP32-S3 Dub Siren")
        self.root.minsize(760, 610)
        self.audio_queue: queue.Queue[bytes] = queue.Queue(maxsize=12)
        self.ui_events: queue.Queue[tuple[str, object]] = queue.Queue()
        self.transport = SerialTransport(
            self.audio_queue,
            lambda status: self.ui_events.put(("status", status)),
        )
        self.player = AudioPlayer(self.audio_queue)
        self.protocol_ok = False
        self.i2s_ready: bool | None = None
        self.streaming = False
        self.active_output: str | None = None
        self.pending_sends: dict[str, str] = {}
        self.sliders: dict[str, SliderControl] = {}
        self.momentary_active: set[str] = set()

        self.port_var = tk.StringVar()
        self.connection_var = tk.StringVar(value="Disconnected")
        self.mode_var = tk.StringVar(value="SINE1")
        self.profile_var = tk.StringVar(value="EXTENDED")
        self.classic_pitch_var = tk.StringVar(value="MID")
        self.classic_mod_var = tk.StringVar(value="MEDIUM")
        self.lfo_shape_var = tk.StringVar(value="CLASSIC")
        self.hold_var = tk.BooleanVar(value=False)
        self.output_var = tk.StringVar(value="Both")

        self._build_ui()
        self.refresh_ports()
        self.root.after(50, self._poll_ui_events)
        self.root.bind_all("<ButtonRelease-1>", self._global_release, add="+")
        self.root.protocol("WM_DELETE_WINDOW", self.close)

    def _build_ui(self) -> None:
        outer = ttk.Frame(self.root, padding=10)
        outer.pack(fill="both", expand=True)

        connection = ttk.LabelFrame(outer, text="CONNECTION", padding=8)
        connection.pack(fill="x", pady=(0, 10))
        ttk.Label(connection, text="COM").pack(side="left")
        self.port_combo = ttk.Combobox(
            connection, textvariable=self.port_var, state="readonly", width=18
        )
        self.port_combo.pack(side="left", padx=6)
        ttk.Button(connection, text="Refresh", command=self.refresh_ports).pack(
            side="left", padx=3
        )
        self.connect_button = ttk.Button(
            connection, text="Connect", command=self.toggle_connection
        )
        self.connect_button.pack(side="left", padx=3)
        ttk.Label(connection, text="Output").pack(side="left", padx=(12, 0))
        self.output_combo = ttk.Combobox(
            connection,
            textvariable=self.output_var,
            values=tuple(OUTPUT_VALUES),
            state="readonly",
            width=10,
        )
        self.output_combo.pack(side="left", padx=6)
        self.output_combo.bind("<<ComboboxSelected>>", self._output_changed)
        self.audio_button = ttk.Button(
            connection,
            text="Start Audio",
            command=self.toggle_audio,
            state="disabled",
        )
        self.audio_button.pack(side="left", padx=3)
        ttk.Label(connection, textvariable=self.connection_var).pack(
            side="right", padx=6
        )

        profile_row = ttk.Frame(outer)
        profile_row.pack(fill="x", pady=(0, 10))
        ttk.Label(profile_row, text="Profile:").pack(side="left")
        self.profile_combo = ttk.Combobox(
            profile_row, textvariable=self.profile_var,
            values=("CLASSIC", "EXTENDED"), state="readonly", width=14,
        )
        self.profile_combo.pack(side="left", padx=8)
        self.profile_combo.bind("<<ComboboxSelected>>", self._profile_changed)

        columns = ttk.Frame(outer)
        columns.pack(fill="both", expand=True)
        siren = ttk.LabelFrame(columns, text="SIREN", padding=8)
        echo = ttk.LabelFrame(columns, text="ECHO", padding=8)
        siren.grid(row=0, column=0, sticky="nsew", padx=(0, 5))
        echo.grid(row=0, column=1, sticky="nsew", padx=(5, 0))
        columns.columnconfigure(0, weight=1)
        columns.columnconfigure(1, weight=1)
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

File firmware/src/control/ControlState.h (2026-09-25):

#pragma once

#include <Arduino.h>

enum class SirenMode {
    Sine1,
    Sine2,
    TestTone,
    Square,
};

enum class LfoShape {
    Classic,
    Triangle,
    Square,
    SawUp,
    SawDown,
    AsymUp,
    AsymDown,
    Pulse25,
    Pulse75,
    Manual,
};

enum class PerformanceProfile { Classic, Extended };
enum class ClassicPitch { Low, Mid, High };
enum class ClassicModulation { Slow, Medium, Fast, Manual };

struct ControlState {
    PerformanceProfile profile = PerformanceProfile::Extended;
    ClassicPitch classicPitch = ClassicPitch::Mid;
    ClassicModulation classicModulation = ClassicModulation::Medium;
    SirenMode mode = SirenMode::Sine1;
    float tuneHz = 220.0f;
    LfoShape lfoShape = LfoShape::Classic;
    float lfoRateHz = 0.70f;
    float lfoDepthOctaves = 1.0f;
    float decayMs = 120.0f;
    bool trigger = false;
    bool hold = false;
    bool modUp = false;
    bool modDown = false;
    float delayMs = 360.0f;
    float feedback = 0.62f;
    float echoLevel = 0.45f;
    float highPassHz = 60.0f;
    float lowPassHz = 7000.0f;
    bool echoCut = false;
    float masterVolume = 0.50f;
    bool voicingV2 = true;
};

class ControlStore {
public:
    ControlStore() : mutex_(xSemaphoreCreateMutex()) {}

    ~ControlStore() {
        if (mutex_ != nullptr) {
            vSemaphoreDelete(mutex_);
        }
    }

    ControlState snapshot() const {
        ControlState copy;
        if (mutex_ != nullptr &&
            xSemaphoreTake(mutex_, portMAX_DELAY) == pdTRUE) {
            copy = state_;
            xSemaphoreGive(mutex_);
        }
        return copy;
    }

    void set(const ControlState &state) {
        if (mutex_ != nullptr &&
            xSemaphoreTake(mutex_, portMAX_DELAY) == pdTRUE) {
            state_ = state;
            xSemaphoreGive(mutex_);
        }
    }

private:
    mutable SemaphoreHandle_t mutex_;
    ControlState state_;
};

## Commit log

2026-09-26 Add KiCad V0 mechanical and electrical PCB
    [ESP-DubSiren.kicad_pcb, ESP-DubSiren.kicad_sch, Hammond_29830PSLA.stp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]
2026-09-26 Save KiCad project settings and ignore local state
2026-09-26 pcb: add ESP32-S3 mainboard V1 preproduction design
2026-09-27 Make echo filter a primary performance control
2026-09-27 Test front-panel echo filter mapping
2026-09-27 Align panel spec with primary echo filter control
2026-09-27 Clear debounced echo-filter send state
2026-09-29 Add support for ESP32-S3 DevKitC-1-N16R8 and implement display asset management
    - Created board configuration file for ESP32-S3 DevKitC-1-N16R8.
    - Added DisplayAssets header and source files for managing display assets.
    - Implemented a Python script to build display assets from PNG images and generate corresponding C++ code.
    - Added unit tests for scene rendering and display asset generation to ensure correctness and determinism.
2026-09-29 Aggiungi supporto per il profilo classico e implementa la voce Sine1 con parametri di modulazione
2026-09-29 Aggiungi supporto per Sine2 esteso e aggiorna i parametri di guadagno
2026-09-30 Aggiorna la calibrazione del profilo Classic con valori di frequenza corretti e aggiungi test per la calibrazione
2026-09-30 Add MCP Bridge plugin with various handlers for editor functionality
    - Implemented SceneHandler for scene manipulation (add, remove, reparent nodes, etc.)
    - Added ScreenshotHandler for capturing editor and game viewports
    - Created ScriptHandler for managing scripts attached to nodes
    - Introduced SignalHandler for listing and managing signals between nodes
    - Developed ValueCoerce utility for converting JSON values to Godot Variant types
    - Established BridgeProtocol for handling JSON-RPC communication
    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
2026-10-02 pcb-v2: checkpoint schematic and 5393 migration
2026-10-02 pcb-v2: quantify Hammond depth conflict and save enclosure study
2026-10-02 pcb-v2: add validated Bourns controls and USB input slew stage
2026-10-02 pcb-v2: record independent audit and remaining MX2A evidence gap
2026-10-02 pcb-v2: complete schematic with verified native CHERRY footprints
2026-10-02 pcb-v2: save routed and mechanical checkpoint at requested stop
2026-10-03 Enhance virtual transport functionality and panel settings
    - Updated `test_virtual_transport.py` to improve test coverage for menu interactions and display states.
    - Modified `virtual_transport.py` to include new API functions for menu items, overlays, and pot configurations.
    - Added comprehensive tests in `dsp_test.cpp` for configurable panel settings and button actions.
    - Implemented new panel settings structure in `PanelSettings.h` to support extended functionality and validation.
    - Enhanced `virtual_esp.cpp` with additional API functions for retrieving pot and button configurations.
2026-10-04 Document waveform research and current voicing
2026-10-04 Align architecture docs with current voicing
2026-10-04 Enhance audio engine and UI for Extended profile with new Sonar mode
    - Updated SINE 1 and SINE 2 definitions to include PolyBLEP pulse and harmonics.
    - Introduced Extended SONAR mode with amplitude pulses and LFO control.
    - Modified encoder behavior in Extended Home to adjust Depth and waveform variants.
    - Improved audio rendering logic for Sonar mode, ensuring proper gate handling.
    - Refactored Oscillator methods to streamline voice rendering and remove legacy code.
    - Added tests for new Sonar functionality and encoder gestures in Extended profile.
    - Updated documentation to reflect changes in controls and audio behavior.
2026-10-15 Save incomplete PCBV2-with-screen CAD and KiCad checkpoint
    Preserve the original V2. Save Hammond CAD studies, grouped components, the renamed KiCad project and local libraries, and reports documenting pending mechanical checks, placement, and inherited copp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
2026-10-18 Consolidate hardware project and remove obsolete routing and CAD
2026-10-18 Prepare issue 14 Gate A panel study in original Hammond enclosure
2026-10-18 Record decision to replace RCA connector after height audit
2026-10-18 Use selected LFO pitch curve for Extended Two Tone (#7)
2026-10-18 Add bypassable dry Tone and signed filter Contour in Extended (#8)
2026-10-18 Add compensated echo Color and finite 2 ms wet cut (#9)
2026-10-18 Add schematic-backed standalone panel input and independent local audio (#12)
2026-10-22 Align echo and debug UI documentation with current controls
2026-10-30 docs(hardware): record standalone exposed-PCB design decision
2026-10-30 docs(hardware): switch active scope from Hammond to exposed PCB
2026-10-30 docs: update hardware scope to standalone exposed PCB
2026-10-30 Review electrical design and propose standalone PCB layout (#34, #35)
2026-10-30 Increase control clearances on 86x126 standalone PCB
2026-10-30 Add illustrative oblique 3D assembly view
2026-10-31 Add issue 36 front silkscreen, assembly guide and review previews
2026-10-31 Preserve accepted issue 36 silkscreen cleanup and local corrections
2026-10-31 Clarify confirmed header mounting for issue 38 display
2026-11-07 Add GND planes and stitching vias to recovered routing candidate
    Keep the recovered 820-segment / 67-via autorouting unchanged and add
    GND pours on F.Cu and B.Cu, 109 GND stitching vias (24 next to GND SMD
    pads, 85 on an 8 mm grid) and a short B.Cu GND stub that fixes the RV3.1
    starved thermal. All edits made live in KiCad 10.0.6 through Konnect.
    DRC: 0 unconnected, no new violations; the 18 U5/U6 courtyard errors
    remain open pending mechanical stack verification.
2026-11-07 Accept DAC-behind-display stack and clear recovered board DRC errors
    Document the U6-behind-U5 stack chosen by the user: DAC on the back,
    display on the front, no DAC jack or screws. Projecting the Adafruit 5393
    back-side parts shows uncut U6 pins (1.40 mm) do not fit the 2.50 mm
    header gap, so the assembly note requires trimming them flush and a dry
    fit against the undocumented microSD socket height.
    Exclude the 18 U6/U5 courtyard errors per item with a comment pointing
    to the note, and mark mounting holes H1-H4 board-only. DRC: 0 errors,
    0 unconnected; 64 parity warnings for footprint fields remain.
2026-11-07 Promote recovered routing to main board and record current PCB checks
    Copy the recovered candidate (GND planes, U5/U6 stack exclusions) into
    ESP-DubSiren.kicad_pcb/.kicad_pro, keep schematic-updated footprint fields,
    and document DRC, power and USB checks in hardware/docs/pcb-corrente.md.
2026-11-07 Restore library fabrication types and 3D models on main board footprints
    Copy only the footprint type (SMD/through-hole) and 3D model references
    from the source libraries for C1-C11, R1-R21, D1, F1, J1, RV1-RV7,
    SW1-SW7 and U1-U7. Pads, copper, fields and silkscreen are unchanged.
    J2 keeps its Neutrik STEP; H1-H4 and TP1-TP7 are left as they were.
    DRC: 0 errors (18 U5/U6 exclusions), 0 unconnected, 0 parity;
    library mismatches drop from 64 to 8 (J2, TP1-TP7).
2026-11-07 Add vendor and datasheet-based 3D models for all main board parts
    Bourns STEP files for PTV111-3/-1 (RV1-RV7, RV7 shaft lengthened to 20 mm)
    and PEC11R (SW7), Espressif ESP32-S3-WROOM-1U (U1) and Adafruit 6250 without
    its jack (U6, 2.5 mm header offset). CHERRY MX2A, PTS636 SM43, Bel 0ZCG and
    MPM3612 are built in FreeCAD from datasheet dimensions. All models are
    aligned to footprint coordinates; scripts in hardware/tools rebuild and
    assign them. Per-group STEP export commands are in cad/3dmodels/README.md.
    Pin-in-hole and board interference checks found mounting slot positions in
    the Bourns_PTV111-3, Bourns_PTV111-1 and PEC11R footprints that do not match
    the Bourns recommended layouts; doc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
2026-11-07 Correct Bourns mounting slots and reroute affected tracks
    Align the NPTH apertures of Bourns_PTV111-3 (centres +/-5.8), PTV111-1
    (+/-6.1) and PEC11R (1.8 x 2.6 at +/-5.7) with the Bourns recommended PCB
    layouts, in the local library and on the board. Reroute MASTER, BTN1,
    USB_DP_CONN, POT7_TOP and ENC_B around the new apertures (via Konnect MCP).
    DRC: 0 errors (18 U5/U6 exclusions), 0 unconnected, 0 parity. STEP check:
    only snap-in barb contact remains at the mounting legs.
2026-11-08 Improve hand-soldering clearances, set black/ENIG stackup and clean up repository
    PCB:
    - Move R8-R10 away from the dummy pin 4 of RV1-RV3 and C5/C6/C7/C9/R6 away
    from U1; reroute the affected tracks locally.
    - Move signal vias to at least 0.5 mm from other-net pads where space allows
    (two remain at 0.468 and 0.377 mm); rework the U3 fan-out.
    - Reposition overlapping silkscreen references.
    - Correct the U1 Fab outline and courtyard to the Espressif land pattern.
    - Set black solder mask, white silkscreen and ENIG finish in the stackup.
    - DRC: 0 errors (18 intended U5/U6 exclusions), 0 unconnected, 0 parity.
    Cleanup:
    - Remove the diagnostic PCB copies, the Freerouting export tool, the unus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
2026-11-08 Add JLCPCB Gerber and drill export and record production checks
    Gerber X2, Excellon PTH/NPTH and drill maps exported with KiCad 10.0.6,
    plus the zip to upload. Document export settings, hole counts, the
    extra DRC against JLCPCB minimums and the two accepted deviations
    (J1 annular ring per GCT land pattern, thin silkscreen).
2026-11-08 Add knob 3D models on potentiometers and encoder
    Same Sky SAK-023 from the vendor STEP on SW7; Davies 1100 (RV1-RV6) and Cliff K85M CL170805B (RV7) as datasheet envelopes. Knobs are a second model on the same footprints, fully seated on the shaft t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
2026-11-08 Record DigiKey order and switch C1-C9 capacitor MPNs to the parts bought
    C1, C3, C5 become Taiyo Yuden LMK212BJ226MG-T and C2, C4, C6, C8, C9 KEMET C0603C104K4RACTU in schematic, PCB and BOM (same 0805/0603 packages). acquisti.csv now holds the 2026-11-08 order; the order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
2026-11-08 Fix audit issues #40-#47 that need no board
    DSP (#41, #45):
    - ECHO LOOP copies the stored sample instead of rewriting the interpolated
    read, so fractional echo times no longer darken the frozen loop.
    - Syndrum keeps the 20 ms minimum decay at DECAY 0; leaving Extended fades
    the Tone filter over 5 ms instead of dropping it; float kTwoPi replaces
    the double TWO_PI in the audio path; SYNDRUM_SWEEP is +/-4 oct everywhere.
    - Voicing and calibration values are unchanged.
    Firmware (#40, #44):
    - STATUS only from the periodic 200 ms path, not after every command.
    - NVS written once settings are stable for 2 s; retried on failure.
    - Pad family/variant persist from both Home and the SOUND menu.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
